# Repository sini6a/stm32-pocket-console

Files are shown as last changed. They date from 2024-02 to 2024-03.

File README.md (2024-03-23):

# STM32 Pocket Game/Dev Console 🕹️

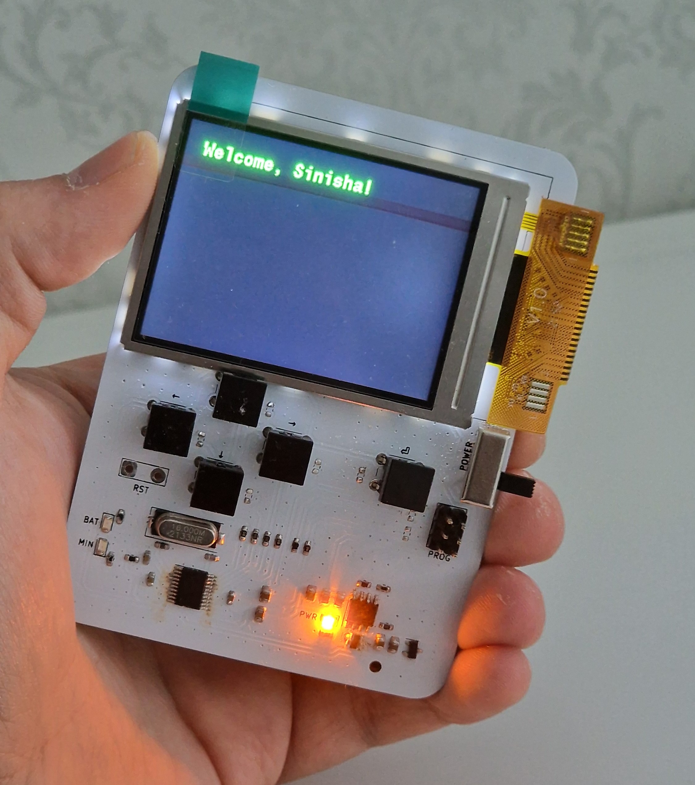
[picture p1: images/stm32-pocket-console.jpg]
screenshot #1


The STM32 Pocket Game/Dev Console 🕹️ is a handheld device powered by 2xAAA batteries. This compact console features 5 programmable buttons, 2 LEDs, and an SPI TFT 2.4" display with a resolution of 320x240 pixels.

Originally equipped with a TagConnect connector for programming, the board underwent a redesign, now featuring a basic 2.54mm pitch connector for enhanced programming flexibility.

Measuring only 97x70mm, this board is designed to be easily customized for various purposes according to your specific needs.

## Key Features:

-   Powered by 2xAAA batteries for portability.
-   5 programmable input buttons for versatile interaction.
-   2 LEDs for status indication.
-   Battery voltage monitoring through analog readings.
-   2.4" SPI TFT display with a resolution of 320x240 pixels.
-   2.54mm pitch connector for programming convenience.

## Manufacturing:

PCBWay generously sponsored the production of this board, providing top-notch PCB manufacturing services. The boards were carefully packaged and demonstrated excellent quality. I was delighted to receive them at my destination within just a week of placing the order.

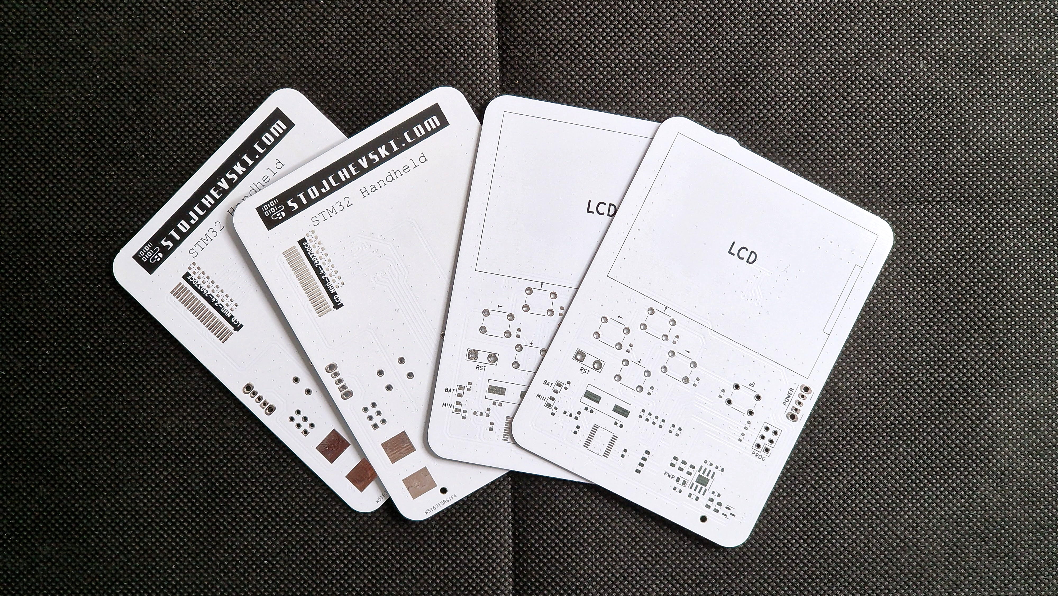
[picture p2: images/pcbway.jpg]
PCBWay PCB


Beyond their exceptional manufacturing capabilities, PCBWay offers additional services such as PCB assembly, 3D printing, and CNC machining. These services empower you to transform your project into a comprehensive, ready-to-use product that can be easily sold or instantly put into use.

If you're interested in building this device, you can find the manufacturing files in the `/gerbers` folder. Head to [PCBWay](https://www.pcbway.com/) to get your boards manufactured.

## Programming:

This board is compatible with various STM32 programmers, including ST-Link and J-Link. I used a cheaper programmer called DAPLINK from AliExpress, as shown in the image below, for the actual programming. Make sure to check the schematics to match the exposed SWD interface with your programmer.

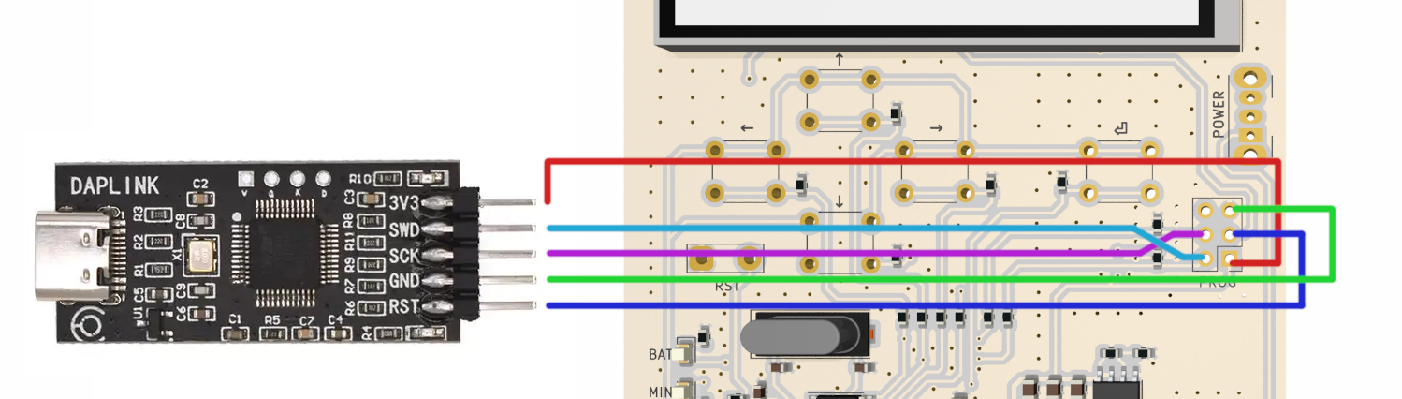
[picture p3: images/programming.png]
programming


## Customization:

The compact size of 97x70mm allows for easy customization, making it adaptable to different use cases based on your requirements.

Feel free to explore the possibilities and unleash the potential of the STM32 Pocket Game/Dev Console for your unique projects!

### Disclaimer:

This project is still a work in progress as the software has not been officially completed, and additional tests are pending to ensure the stability and performance of the device. Stay tuned for updates, or feel free to build one yourself if you enjoy experimenting.

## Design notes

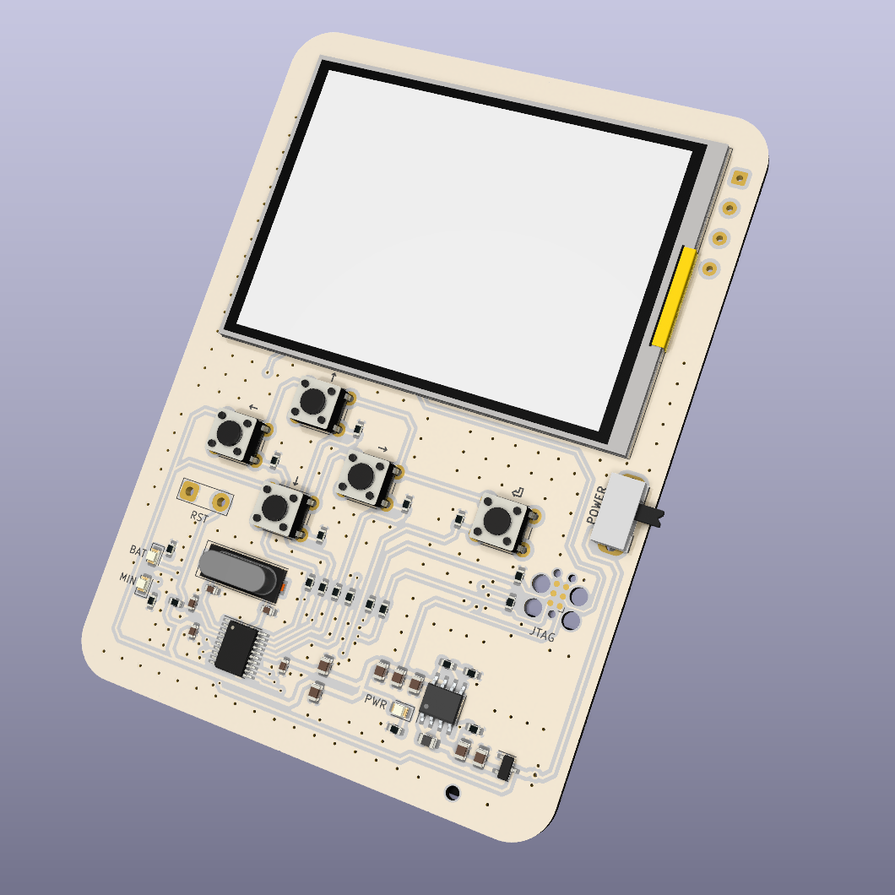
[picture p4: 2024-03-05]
images/stopwatchy-kicad.png

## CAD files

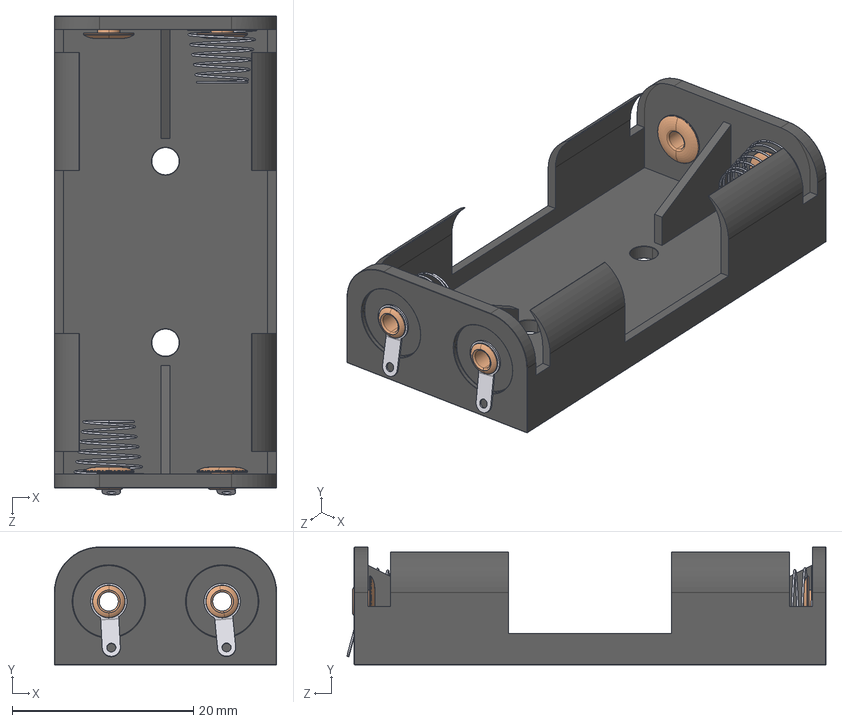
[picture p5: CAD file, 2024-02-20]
KiCad/3d/koszyk 2xAAA_214.STEP
24.5 x 13.0 x 52.8 mm
battery holder 2 x AAA
wtyczka x 2
wstawka x 4
sprezyna x 2

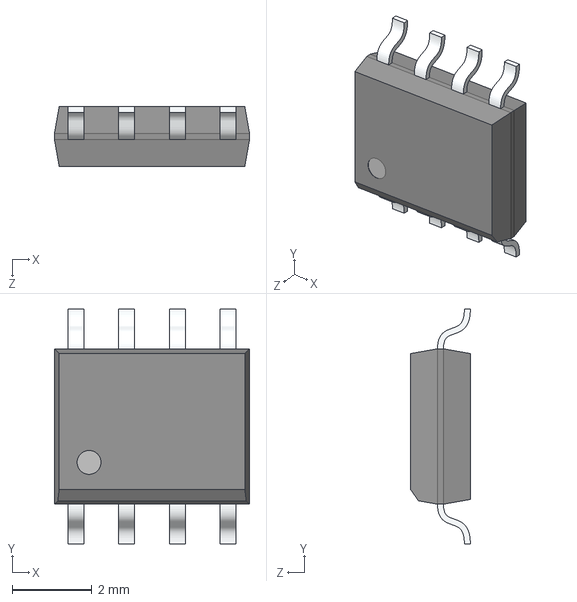
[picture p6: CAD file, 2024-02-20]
KiCad/3d/SOIC8.STEP
4.90 x 5.90 x 1.50 mm

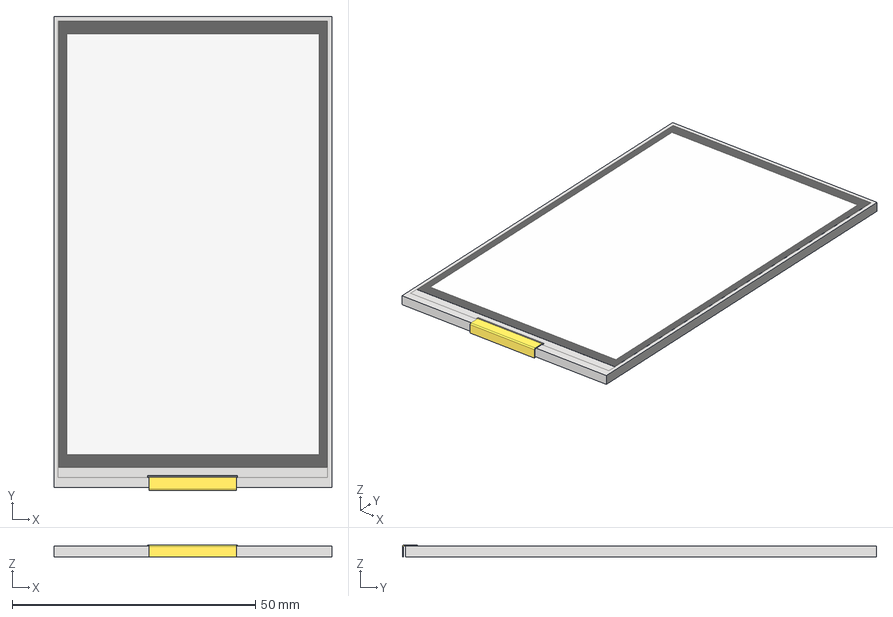
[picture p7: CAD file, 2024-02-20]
KiCad/3d/FRD400H25027-A.STEP
57.1 x 97.5 x 2.46 mm

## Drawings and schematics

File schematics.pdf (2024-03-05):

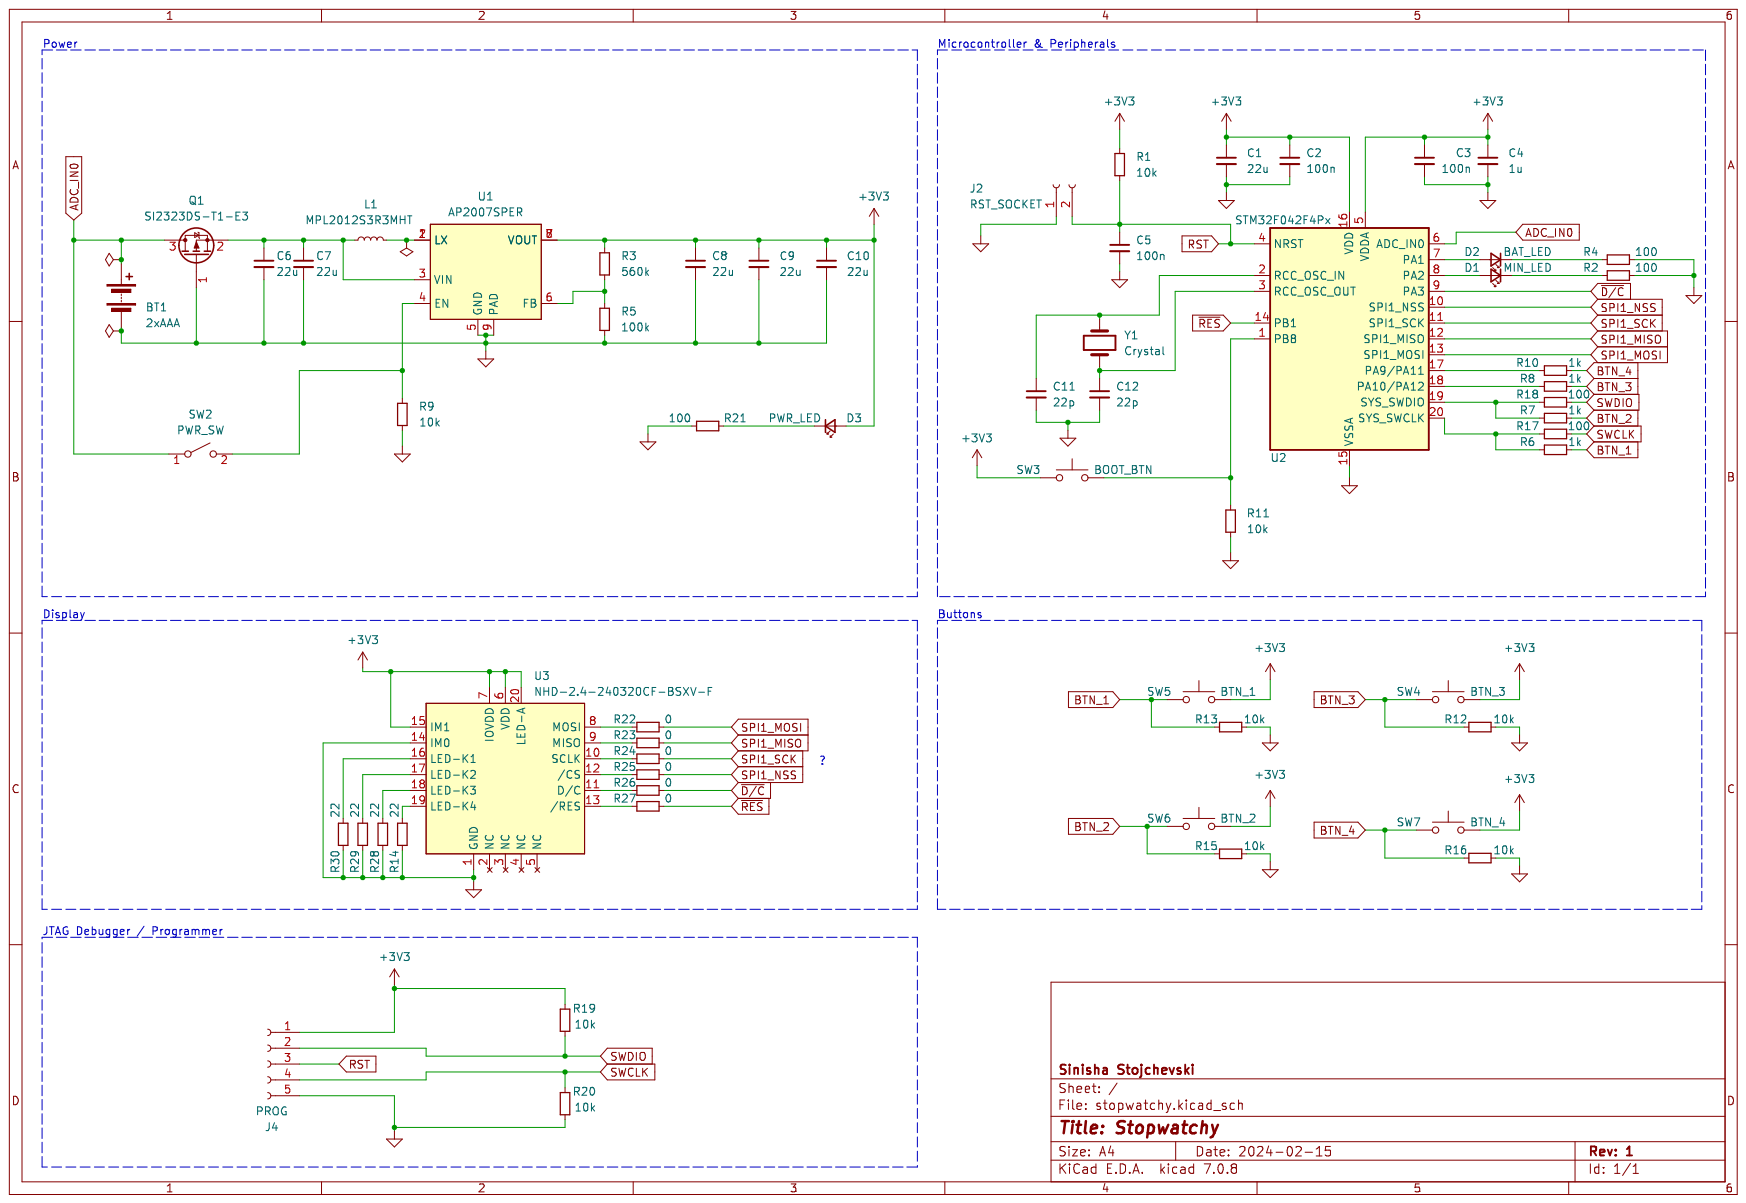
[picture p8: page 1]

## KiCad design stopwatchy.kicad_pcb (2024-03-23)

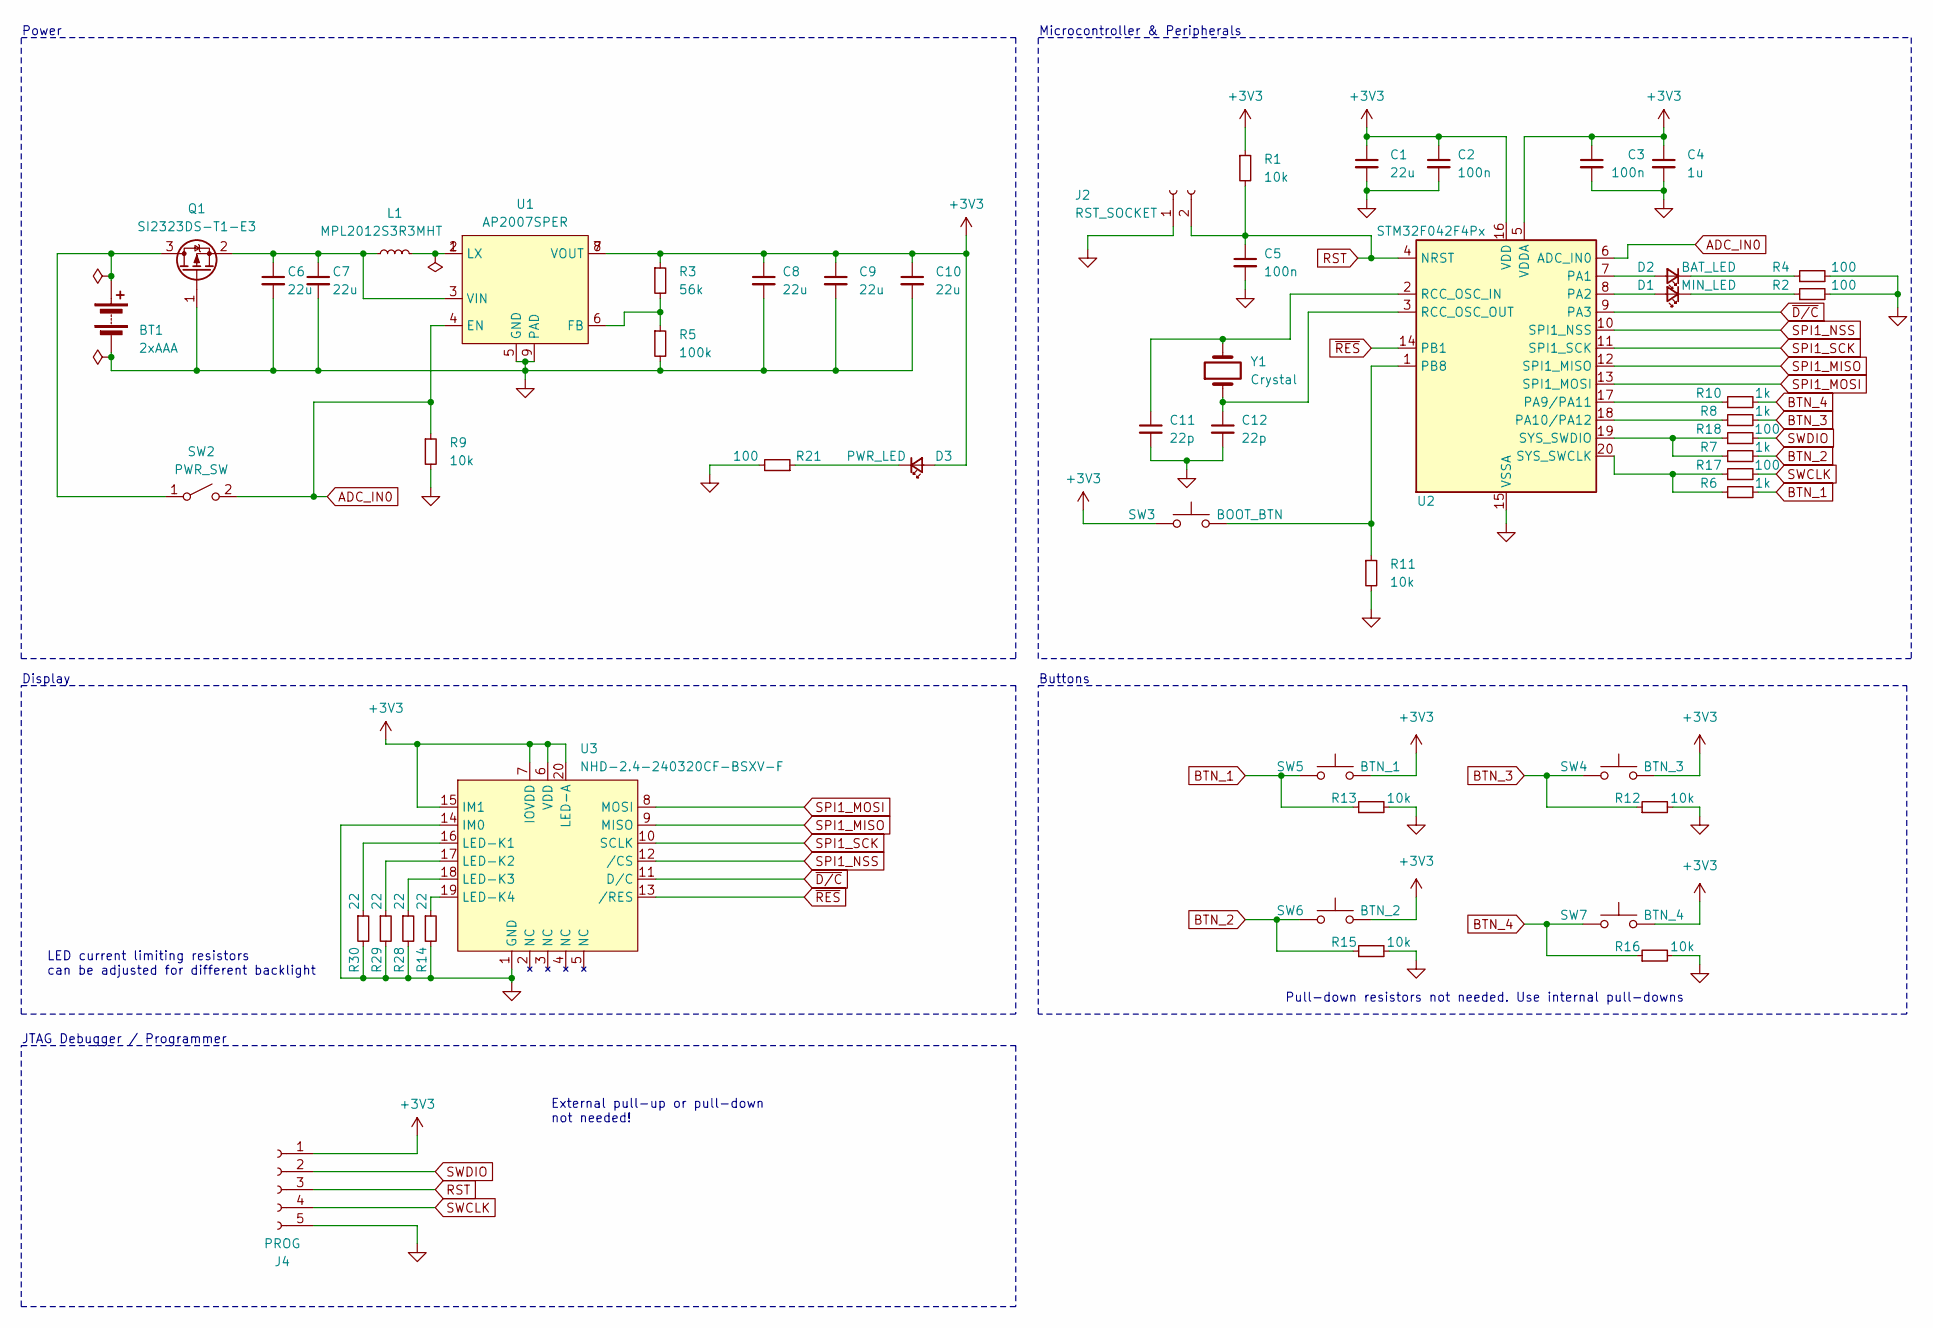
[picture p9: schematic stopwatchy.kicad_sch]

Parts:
BT1: 2xAAA; BH-AAA-B5AK001; LCSC C964882
C1, C6, C7, C8, C9: 22u; C_0805_2012Metric; LCSC C45783
C2, C3: 100n; C_0603_1608Metric; LCSC C14663
C4: 1u; C_0805_2012Metric; LCSC C28323
C5: 100n; C_0603_1608Metric
C10: 22u; C_0805_2012Metric
C11, C12: 22p; C_0603_1608Metric; LCSC C1653
D1: MIN_LED; LED_0805_2012Metric; LCSC C2297
D2: BAT_LED; LED_0805_2012Metric; LCSC C2296
D3: PWR_LED; LED_0805_2012Metric; LCSC C84256
J2: RST_SOCKET; TestPoint_2Pads_Pitch5.08mm_Drill1.3mm
J4: PROG; PinHeader_2x03_P2.54mm_Vertical
L1: MPL2012S3R3MHT; L_0805_2012Metric
Q1: SI2323DS-T1-E3; SOT-23; LCSC C141511
R1, R9, R11, R12, R13, R15, R16: 10k; R_0603_1608Metric; LCSC C25804
R2, R4, R17, R18, R21: 100; R_0603_1608Metric; LCSC C22775
R3: 56k; R_0603_1608Metric; LCSC C25602
R5: 100k; R_0603_1608Metric; LCSC C25803
R6, R7, R8, R10: 1k; R_0603_1608Metric; LCSC C21190
R14, R28, R29, R30: 22; R_0603_1608Metric; LCSC C22775
SW2: PWR_SW; SW_CuK_OS102011MA1QN1_SPDT_Angled; LCSC C2681575
SW3: BOOT_BTN; SW_PUSH_6mm
SW4: BTN_3; SW_PUSH_6mm
SW5: BTN_1; SW_PUSH_6mm
SW6: BTN_2; SW_PUSH_6mm
SW7: BTN_4; SW_PUSH_6mm
U1: AP2007SPER; SOIC-8-1EP_3.9x4.9mm_P1.27mm_EP2.41x3.3mm; LCSC C130338
U2: STM32F042F4Px; TSSOP-20_4.4x6.5mm_P0.65mm; LCSC C81002
U3: NHD-2.4-240320CF-BSXV-F
Y1: Crystal; Crystal_SMD_HC49-SD

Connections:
+3V3: C1.1, C2.1, C3.1, C4.1, C8.1, C9.1, C10.1, D3.2 (A), J4.1, R1.1, R3.1, SW3.1, SW4.2, SW5.2, SW6.2, SW7.2, U1.7 (VOUT), U1.8 (VOUT), U2.5 (VDDA), U2.16 (VDD), U3.6 (VDD), U3.7 (IOVDD), U3.15 (IM1), U3.20 (LED-A)
ADC_IN0: R9.1, SW2.2 (B), U1.4 (EN), U2.6 (ADC_IN0)
BTN_1: R6.2, R13.1, SW5.1
BTN_2: R7.2, R15.1, SW6.1
BTN_3: R8.2, R12.1, SW4.1
BTN_4: R10.2, R16.1, SW7.1
GND: BT1.2 (-), C1.2, C2.2, C3.2, C4.2, C5.2, C6.2, C7.2, C8.2, C9.2, C10.2, C11.2, C12.2, J2.1, J4.5, Q1.1 (G), R2.2, R4.2, R5.2, R9.2, R11.2, R12.2, R13.2, R14.2, R15.2, R16.2, R21.2, R28.2, R29.2, R30.2, U1.5 (GND), U1.9 (PAD), U2.15 (VSSA), U3.1 (GND), U3.14 (IM0)
unnamed: BT1.1 (+), Q1.3 (D), SW2.1 (A)
unnamed: D1.2 (A), U2.8 (PA2)
unnamed: D1.1 (K), R2.1
unnamed: D2.2 (A), U2.7 (PA1)
unnamed: D2.1 (K), R4.1
unnamed: D3.1 (K), R21.1
unnamed: L1.2, U1.1 (LX), U1.2 (LX)
unnamed: C6.1, C7.1, L1.1, Q1.2 (S), U1.3 (VIN)
unnamed: R3.2, R5.1, U1.6 (FB)
unnamed: R10.1, U2.17 (PA9/PA11)
unnamed: R8.1, U2.18 (PA10/PA12)
unnamed: R7.1, R18.1, U2.19 (SYS_SWDIO)
unnamed: R6.1, R17.1, U2.20 (SYS_SWCLK)
unnamed: R11.1, SW3.2, U2.1 (PB8)
unnamed: C11.1, U2.2 (RCC_OSC_IN), Y1.2
unnamed: C12.1, U2.3 (RCC_OSC_OUT), Y1.1
unnamed: R30.1, U3.16 (LED-K1)
unnamed: R29.1, U3.17 (LED-K2)
unnamed: R28.1, U3.18 (LED-K3)
unnamed: R14.1, U3.19 (LED-K4)
RST: C5.1, J2.2, J4.3, R1.2, U2.4 (NRST)
SPI1_MISO: U2.12 (SPI1_MISO), U3.9 (MISO)
SPI1_MOSI: U2.13 (SPI1_MOSI), U3.8 (MOSI)
SPI1_NSS: U2.10 (SPI1_NSS), U3.12 (/CS)
SPI1_SCK: U2.11 (SPI1_SCK), U3.10 (SCLK)
SWCLK: J4.4, R17.2
SWDIO: J4.2, R18.2
~D/C: U2.9 (PA3), U3.11 (D/C)
~RES: U2.14 (PB1), U3.13 (/RES)

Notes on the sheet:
Display
External pull-up or pull-down not needed!
LED current limiting resistors can be adjusted for different backlight
Microcontroller & Peripherals
Pull-down resistors not needed. Use internal pull-downs
Power
Buttons
JTAG Debugger / Programmer

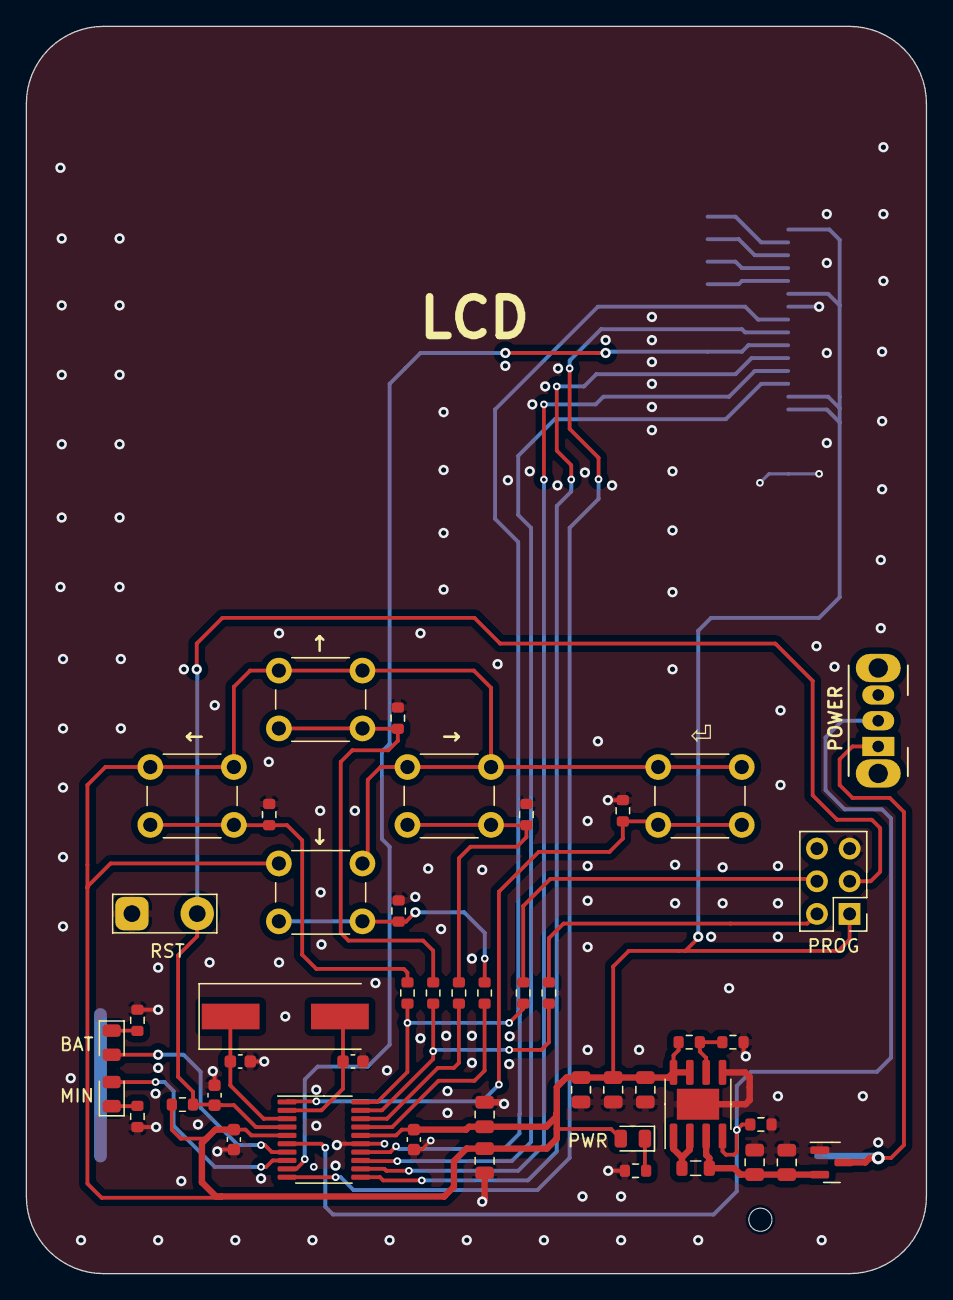
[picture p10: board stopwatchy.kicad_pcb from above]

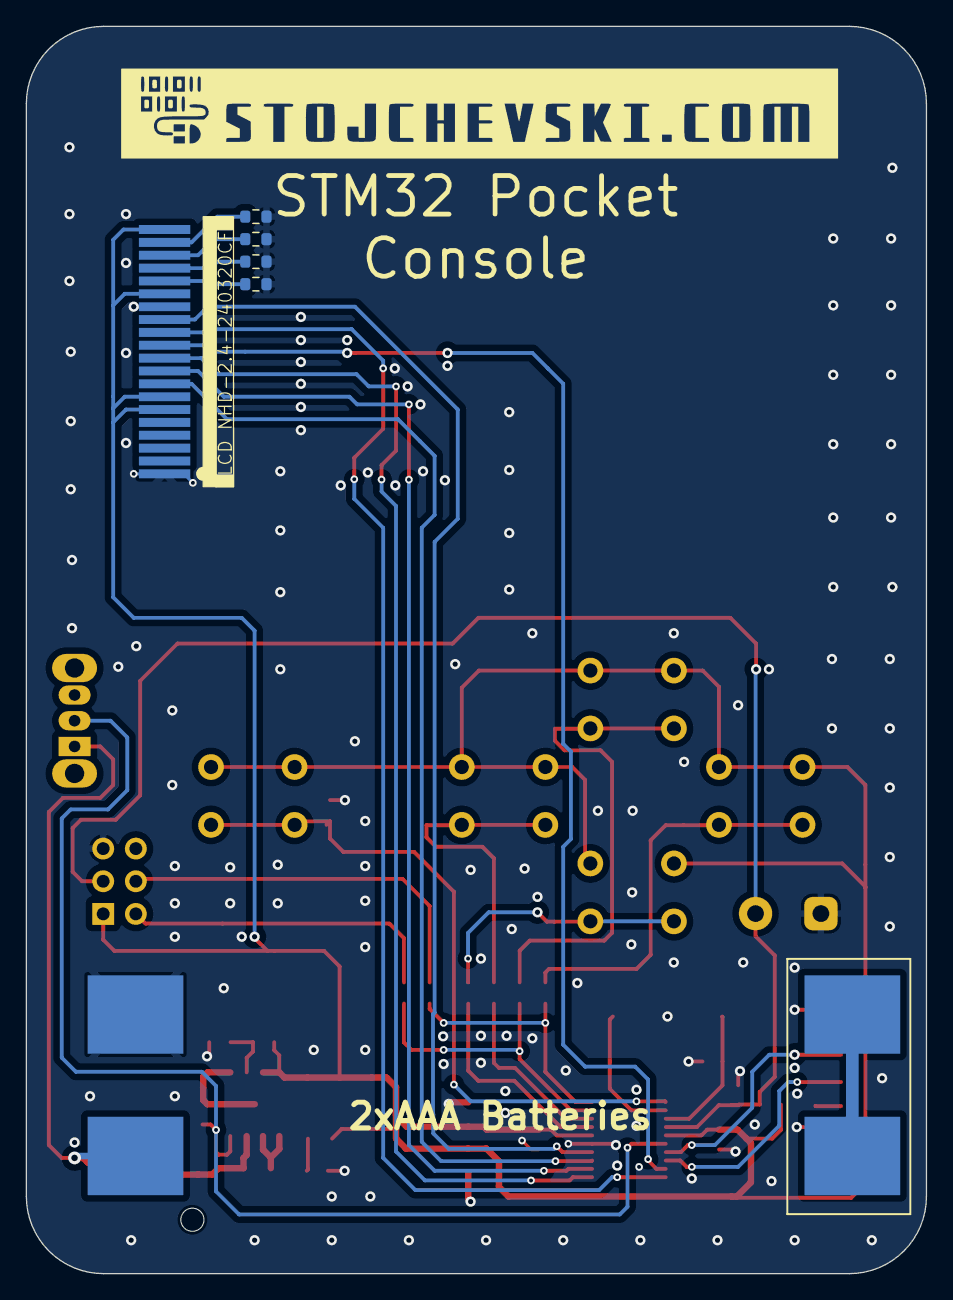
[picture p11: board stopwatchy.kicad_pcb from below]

Board: 2 copper layers, 70.0 x 97.0 mm, 52 parts (6 on the bottom side), 36 nets.

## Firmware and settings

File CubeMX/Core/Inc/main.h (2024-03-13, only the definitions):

#define BAT_LED_Pin GPIO_PIN_1
#define BAT_LED_GPIO_Port GPIOA
#define MIN_LED_Pin GPIO_PIN_2
#define MIN_LED_GPIO_Port GPIOA

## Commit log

2024-03-05 minor improvements in 3d models
    [stopwatchy.kicad_pcb, stopwatchy.kicad_sch]
2024-03-05 added schematics
2024-03-13 updated to ext clock and connected all buttons
2024-03-23 updated adc_in route from switch and changed R1 from 560k to 56k
    [stopwatchy-B_Cu.gbr, stopwatchy-B_Mask.gbr, stopwatchy-B_Paste.gbr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]
2024-03-23 removed unneeded resistors, fixed lcd connector placement, removed vias
    [stopwatchy.kicad_pcb, stopwatchy.kicad_sch]

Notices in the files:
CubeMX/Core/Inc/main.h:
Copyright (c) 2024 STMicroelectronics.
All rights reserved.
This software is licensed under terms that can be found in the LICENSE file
